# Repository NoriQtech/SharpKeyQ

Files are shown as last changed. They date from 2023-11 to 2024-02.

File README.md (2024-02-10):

## はじめに
このプロジェクトは、[engineers@work](https://eaw.app/) によって開発された SharpKey Multi HID Interface について、DIY用のPCB基板を設計し、動作/検証をする試みです。

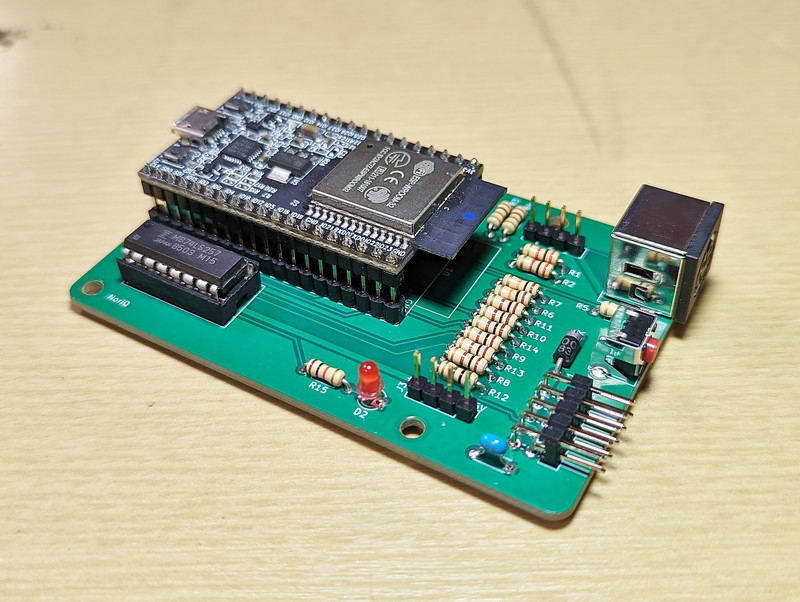
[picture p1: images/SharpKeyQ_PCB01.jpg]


海外のコアな8BitレトロPCファンが日本のユニークな8Bitパソコンを使いこなすために、日夜、解析・研究を行い、今も新しいプロダクトを生み出していることに敬意を表します。

## オリジナル
SharpKey Multi HID Interface のオリジナルプロジェクトについては、下記を参照してください。

* [engineers@work](https://eaw.app/)
* [SharpKey Multi-HID Interface](https://eaw.app/sharpkey/)
* [ユーザーマニュアル](https://eaw.app/sharpkey-usermanual/)
* [テクニカルガイド](https://eaw.app/sharpkey-technicalguide/)
* [GitHub](https://github.com/pdsmart)

## このプロジェクト
このプロジェクトはオリジナルコードからビルド可能な状態に修正を加えたものです。
機能は全てオリジナルに準じます。
また、回路図や基板デザインはDIY可能な設計に置き換えられています。

詳細は下記を参照してください。

[JunkQ yard SharpKeyQ](https://junkqyard.blogspot.com/p/sharpkeyq.html)

## アップデート
2024-02-09 MZ-5665モジュールの対応<br/>
2023-11-26 最初のコミット

## ライセンス
オリジナルライセンスに基づき、SharpKey Multi HID Interface の設計、ハードウェアおよびソフトウェアは、GNU Public License v3 に基づいてライセンスされています。

## The Gnu Public License v3
The source and binary files in this project marked as GPL v3 are free software: you can redistribute it and-or modify it under the terms of the GNU General Public License as published by the Free Software Foundation, either version 3 of the License, or (at your option) any later version.

The source files are distributed in the hope that it will be useful, but WITHOUT ANY WARRANTY; without even the implied warranty of MERCHANTABILITY or FITNESS FOR A PARTICULAR PURPOSE. See the GNU General Public License for more details.

You should have received a copy of the GNU General Public License along with this program. If not, see http://www.gnu.org/licenses/.

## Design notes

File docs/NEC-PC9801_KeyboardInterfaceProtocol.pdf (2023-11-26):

Copyright (C) 1994,1995,1996,1997 Terumasa KODAKA, Takeshi KONO

■ Keyboard interface
Target normal, high resolution, PC-98LT / HA
Tip 8251A (equivalent)
Explanation o In the PC-9800 series, the key input information on the keyboard is a serial signal.
It is sent to the main body at (fixed at 19200bps). Keyboard I / F 8251A (equivalent) is a key input Upon receiving the information, an INT 09h interrupt is generated and the key input is software. Notify (BIOS, etc.).
- Even with models with integrated keyboard and main unit, such as 98NOTE, PC-98LT, HA, etc.
The keyboard and keyboard I / F communicate serially in the same way as a desktop machine.
With the u 98NOTE series, you can connect a full keyboard to the numeric keypad connector. It is possible.
- In the PC-9800 series, the TXD signal line of 8251 is RST # (keyboard connector pin 1). Connected to and originally used for keyboard reset, but with a new key
The board now uses this to send commands.
- For models equipped with a new keyboard, it is possible to send commands to the keyboard. can. [CAPS], [Kana], [NUM] Key lock status acquisition and lock status control,
You can change the key repeat interval.
- The following keyboards are valid for the PC-9800 series.
---------------- + --------------------------------- -------------Old keyboard |
+ -------------- + ---------------------------------- ------------
PC-98LT | [BS], [ROLL UP], [ROLL DOWN], [DEL], [HELP], [COPY]
| | There is no key, but you can substitute it with the following operation.
| | [BS], [DEL] = [DEL BS]
| | [HELP] = [CTRL] + [SHIFT] + [H]
| | [ROLL UP] = [CTRL] + [SHIFT] + [↑]
| | [ROLL DOWN] = [CTRL] + [SHIFT] + [↓]
| | [COPY] = [CTRL] + [SHIFT] + [P]
+ -------------- + ---------------------------------- ------------
| High resolution | PC-98XA / XL / XL ^ 2
+ -------------- + ---------------------------------- ------------
| No NFER | PC-9801 1st generation ・ | E ・ | F ・ | M
+ -------------- + ---------------------------------- ------------
| Others | PC-9801 Other than the first generation, E, F, M
-+ -------------- + --------------------------------- -------------New keyboard |
+ -------------- + ---------------------------------- ------------
| 98NOTE | 98NOTE series
+ -------------- + ---------------------------------- ------------
| PC-9801-98 | Easy keyboard
+ -------------- + ---------------------------------- ------------
| PC-9801-106 | 98 Standard keyboard (Windows key, no menu key)
+ -------------- + ---------------------------------- ------------
PC-9801-114 | PC-PTOS keyboard
+ -------------- + ---------------------------------- ------------
| PC-9801-115 | Bungo DP Keyboard
+ -------------- + ---------------------------------- ------------
PC-9801-116 | 106 keyboard
+ -------------- + ---------------------------------- ------------
| PC-9801-119 | 98 Standard keyboard (Windows key, menu key available)
+ -------------- + ---------------------------------- ------------
| Others | Equivalent to PC-9801-106, PC-9801T-03
-+ -------------- + --------------------------------- -------------Related I / O 0000h bit 1
INT 18h --Function 00 ～ 09h
INT 09h (external interrupt)
0000: 0502 ～ 053Ah

I / O 0041h
Name keyboard interface
function
[READ] Read received data
bit 7-0: Make / Break Code, Status 00-7Fh = Makeup code
80 ～ FFh = Break code
FAh = ACK
FCh = NACK
[WRITE] Write transmission data
bit 7-0: Down command
-------- + ------------------------------------------- ----------
Command | Contents
-------- + ------------------------------------------- ----------
95h | Extended key setting ■ [PC-9801-98 ･ 119] (Undocumented)
| * Output parameters in the 2nd byte
| bit 7 ～ 0:
| 00h = Normal
| 03h = Windows key, application key valid
| ■ [PC-9801-119]
-------- + ------------------------------------------- ----------
96h | Mode identification ■ [PC-9801-98] (Undocumented)
| * A0h, 86h is returned in automatic conversion mode
| * A0h, 85h is returned in normal mode
-------- + ------------------------------------------- ----------
99h | Unknown (Undocumented)
| * FBh is returned
-------- + ------------------------------------------- ----------
9Ch | Keyboard repeat speed setting (Undocumented)
| * Output parameters in the 2nd byte
| bit 7: unused

| bit 6,5: Delay
| 11b = 1000ms
| 10b = 500ms
| 01b = 500ms (default)
| 00b = 250ms
| bit 4 ~ 0: Repeat speed
| 11111b = lowest speed
| 00001b = fastest (default)
-------- + ------------------------------------------- ----------
9Dh | Unknown ■ [PC-9801NS / T] (Undocumented)
| * Output parameters in the 2nd byte
| 00h = Unknown
| 01h = Unknown
-------- + ------------------------------------------- ----------
9Dh | Keyboard LED reading (Undocumented)
| * Send 60h to the 2nd byte
| * LED status is sent in the following format
| bit 7-4: unused
| bit 3: [Kana] LED
| bit 2: [CAPS] LED
| bit 0: [NUM] LED
| 1 = ON
| 0 = OFF
-------- + ------------------------------------------- ----------
9Dh | Keyboard LED settings
| * Output parameters in the 2nd byte
| bit 7-4: Always 0111b
| bit 3: [Kana] LED
| bit 2: [CAPS] LED
| bit 0: [NUM] LED (Undocumented)
| 1 = ON
| 0 = OFF
-------- + ------------------------------------------- ----------
9Eh | Unknown (Undocumented)
-------- + ------------------------------------------- ----------
9Fh | Keyboard type identification
| * A0h, 80h is returned on the new keyboard
-------- + ------------------------------------------- ----------Explanation o Get the make / break code from the keyboard.
- Issue a downlink command to the keyboard. Related I / O 0041h

I / O 0043h
Name keyboard interface
function
[READ] ■ Meaning of bits when reading status bit 7: DSR input terminal
1 = HIGH level
0 = LOW level
* Indicates the status of pin 6 of the keyboard connector. (Undocumented) bit 6: SYNC / BRK
1 = Break detection
0 = None
* Does not occur as long as you have a regular handshake with the keyboard. bit 5: Framing error (FE) detection
1 = Yes
0 = None
bit 4: Overrun error (OE) detection
1 = Yes
0 = None
* Does not occur as long as you have a regular handshake with the keyboard. bit 3: Parity error (PE) detection
1 = Yes
0 = None
bit 2: TxEMP (end of transmission)
bit 1: RxRDY (data reception)
bit 0: TxRDY (can be sent)

[WRITE] ■ Meaning of bits when writing command words
bit 7: enter hunt phase
* Do not use the keyboard I / F because it is synchronized communication. Set to 0. bit 6: 8251A reset
1 = do
0 = No
bit 5: RTS terminal control
1 = RDY # signal line is always inactive
0 = RDY # signal line follows the state of RxRDY
* For keyboard I / F, RDY # signal line (keyboard connector pin 3) Control the operation. It has the following meaning.
bit 4: Clear error flag
1 = Clear FE, OE, PE of 8251A
0 = Do not clear the error
bit 3: TxDATA break transmission
1 = RST # Set signal line to LOW level
0 = RST # Set signal line to HIGH level
* For keyboard I / F, RST # signal line (keyboard connector pin 1)
Control the operation. RST # signal line to LOW level for a period of 13 μs or more Then, the CPU in the keyboard is reset.
bit 2: Acceptance
1 = Receive data from the keyboard
0 = No data received from keyboard
* The keyboard I / F operates as follows. bit 1: DTR signal
1 = Set RTY # signal to HIGH level

0 = RTY # Set signal to LOW level
* For keyboard I / F, RTY # signal line (keyboard connector pin 5) Control the operation. Usually HIGH. When LOW, the data on the keyboard Request a resend.
bit 0: Send permission
1 = RST # Send data from signal line
0 = RST # Do not send data from the signal line
* On the keyboard I / F, issue a downlink command for the keyboard. When using the RST # signal line. Set to 1 when sending a command. [WRITE] ■ Meaning of bits when mode is written
bit 7,6: ST2, ST1 (number of transmission stop bits)
Set 01b (1 bit)
bit 5,4: P1, P0 (parity generation / check)
Set 01b (odd parity)
bit 3,2: L1, L0 (character length)
Set 11b (8 bits)
bit 1,0: B1, B0 (baud rate)
Set 10b (16x clock)

Explanation o Set the mode of the 8251 equivalent used for the keyboard interface. Related I / O 0043h

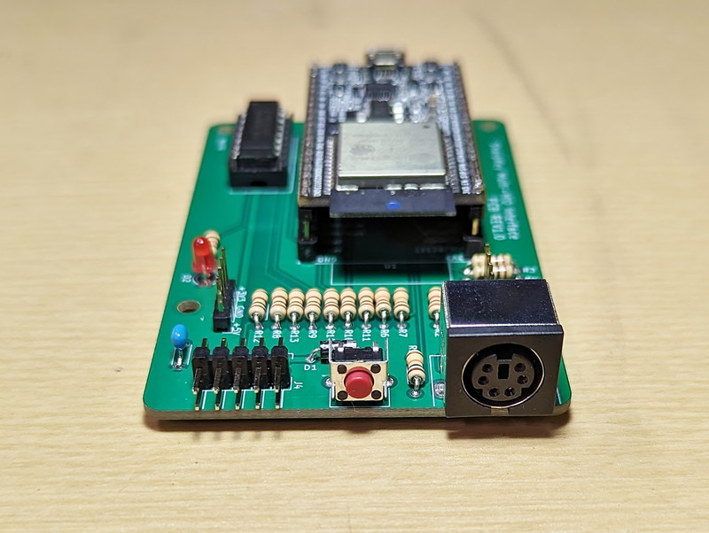
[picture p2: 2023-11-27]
images/SharpKeyQ_PCB02.jpg

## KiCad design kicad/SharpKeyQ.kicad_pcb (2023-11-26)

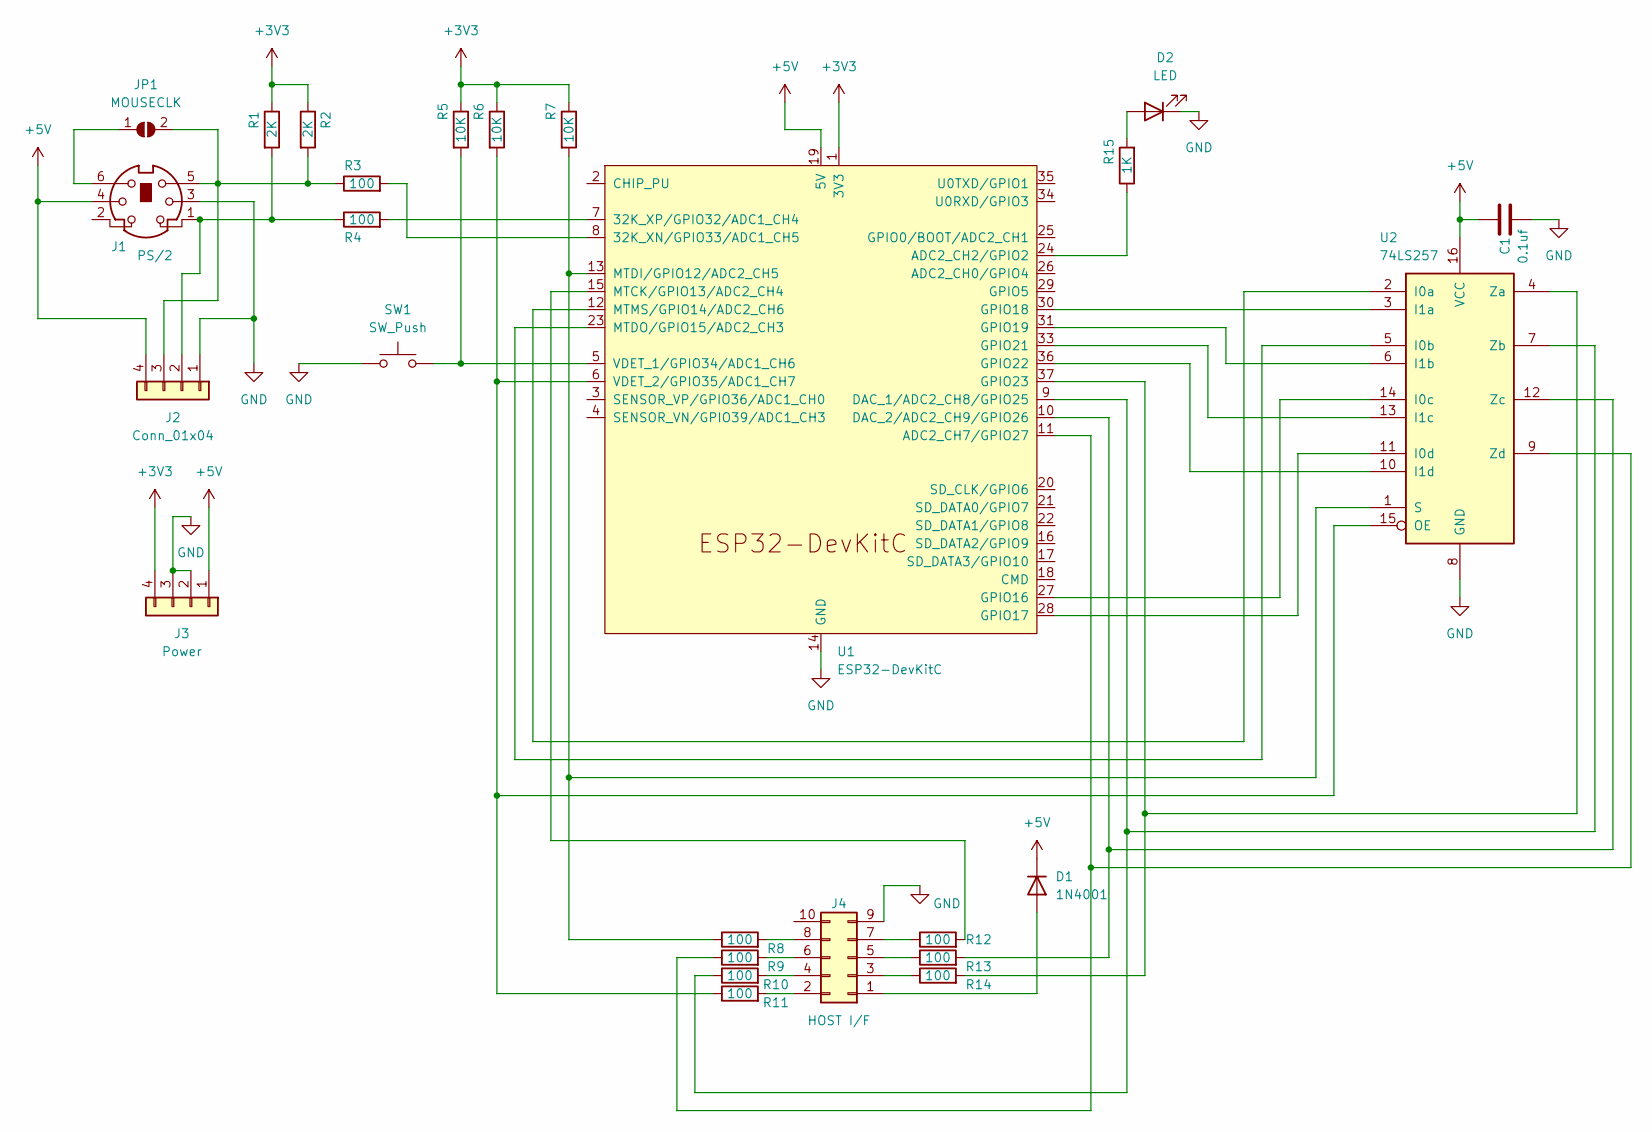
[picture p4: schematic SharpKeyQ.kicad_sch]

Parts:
C1: 0.1uf; C_Disc_D4.3mm_W1.9mm_P5.00mm
D1: 1N4001; D_DO-34_SOD68_P7.62mm_Horizontal
D2: LED; LED_D3.0mm
J1: PS/2; Connector_Mini-DIN_Female_6Pin_2rows
J2: Conn_01x04; PinHeader_1x04_P2.54mm_Vertical
J3: Power; PinHeader_1x04_P2.54mm_Vertical
J4: HOST I/F; PinHeader_2x05_P2.54mm_Horizontal
JP1: MOUSECLK; SolderJumper-2_P1.3mm_Open_RoundedPad1.0x1.5mm
R1, R2: 2K; R_Axial_DIN0204_L3.6mm_D1.6mm_P7.62mm_Horizontal
R3, R4, R8, R9, R10, R11, R12, R13, R14: 100; R_Axial_DIN0204_L3.6mm_D1.6mm_P7.62mm_Horizontal
R5, R6, R7: 10K; R_Axial_DIN0204_L3.6mm_D1.6mm_P7.62mm_Horizontal
R15: 1K; R_Axial_DIN0204_L3.6mm_D1.6mm_P7.62mm_Horizontal
SW1: SW_Push; SW_Tactile_SKHH_Angled
U1: ESP32-DevKitC
U2: 74LS257; DIP-16_W7.62mm_Socket

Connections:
+3V3: J3.4, R1.1, R2.1, R5.1, R6.1, R7.1, U1.1 (3V3)
+5V: C1.1, D1.1 (K), J1.4, J2.4, J3.1, U1.19 (5V), U2.16 (VCC)
GND: C1.2, D2.1 (K), J1.3, J2.1, J3.2, J3.3, J4.9, SW1.2, U1.14 (GND), U1.32 (GND), U1.38 (GND), U2.8 (GND)
unnamed: D1.2 (A), J4.1
unnamed: D2.2 (A), R15.2
unnamed: J1.1, J2.2, R1.2, R4.1
unnamed: J1.5, J2.3, JP1.2 (B), R2.2, R3.1
unnamed: J4.2, R11.2
unnamed: J4.3, R14.1
unnamed: J4.4, R10.2
unnamed: J4.5, R13.1
unnamed: J4.6, R9.2
unnamed: J4.7, R12.1
unnamed: J4.8, R8.2
unnamed: J1.6, JP1.1 (A)
unnamed: R3.2, U1.8 (32K_XN/GPIO33/ADC1_CH5)
unnamed: R4.2, U1.7 (32K_XP/GPIO32/ADC1_CH4)
unnamed: R15.1, U1.24 (ADC2_CH2/GPIO2)
unnamed: R9.1, U1.11 (ADC2_CH7/GPIO27), U2.9 (Zd)
unnamed: R10.1, U1.9 (DAC_1/ADC2_CH8/GPIO25), U2.7 (Zb)
unnamed: R13.2, U1.10 (DAC_2/ADC2_CH9/GPIO26), U2.12 (Zc)
unnamed: U1.27 (GPIO16), U2.14 (I0c)
unnamed: U1.28 (GPIO17), U2.11 (I0d)
unnamed: U1.30 (GPIO18), U2.3 (I1a)
unnamed: U1.31 (GPIO19), U2.6 (I1b)
unnamed: U1.33 (GPIO21), U2.13 (I1c)
unnamed: U1.36 (GPIO22), U2.10 (I1d)
unnamed: R14.2, U1.37 (GPIO23), U2.4 (Za)
unnamed: R12.2, U1.15 (MTCK/GPIO13/ADC2_CH4)
unnamed: R7.2, R8.1, U1.13 (MTDI/GPIO12/ADC2_CH5), U2.1 (S)
unnamed: U1.23 (MTDO/GPIO15/ADC2_CH3), U2.5 (I0b)
unnamed: U1.12 (MTMS/GPIO14/ADC2_CH6), U2.2 (I0a)
unnamed: R5.2, SW1.1, U1.5 (VDET_1/GPIO34/ADC1_CH6)
unnamed: R6.2, R11.1, U1.6 (VDET_2/GPIO35/ADC1_CH7), U2.15 (OE)

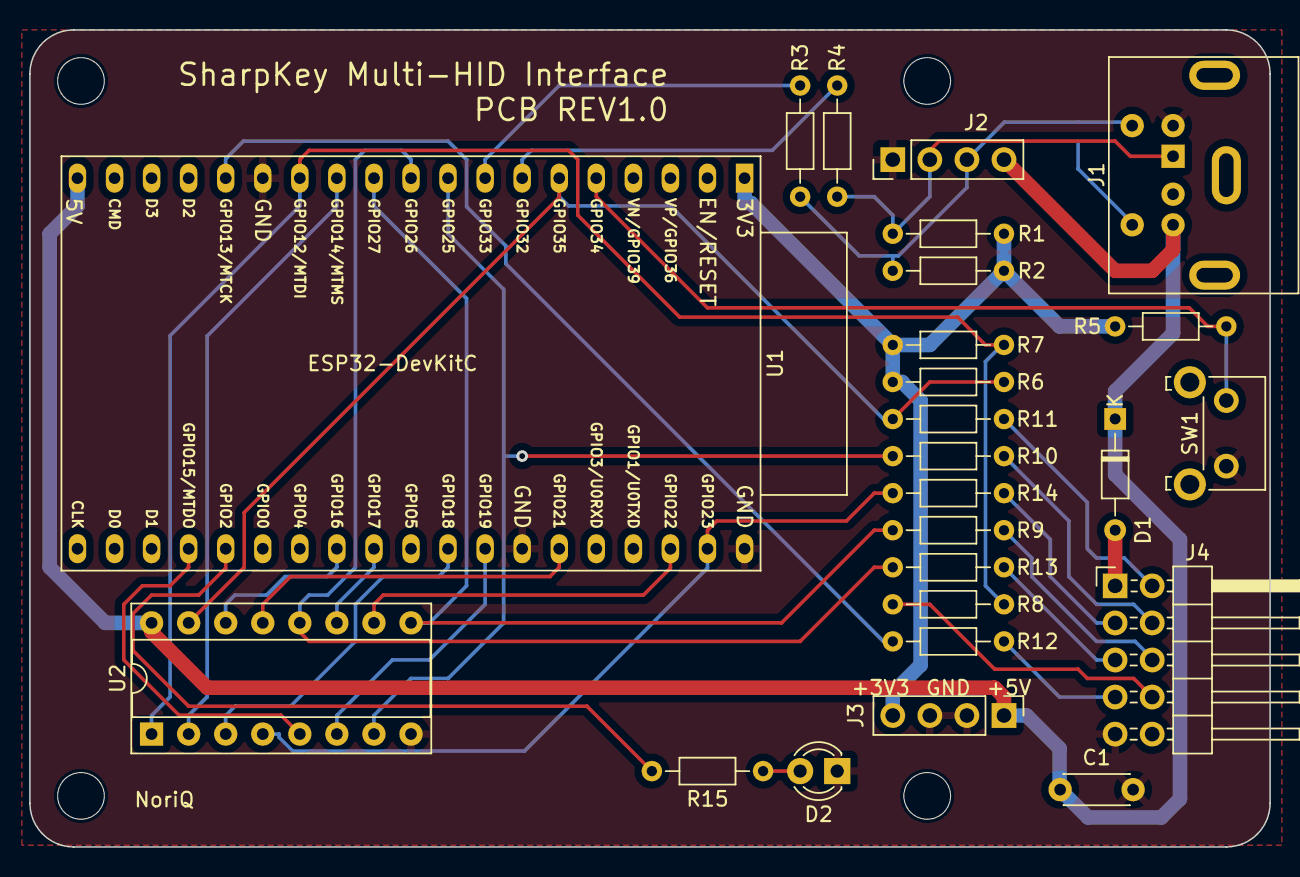
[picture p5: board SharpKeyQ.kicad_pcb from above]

Board: 2 copper layers, 85.0 x 56.0 mm, 30 parts (1 on the bottom side), 34 nets.

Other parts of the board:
REF1, REF2, REF3, REF4: MountingHole_3.2mm_M3

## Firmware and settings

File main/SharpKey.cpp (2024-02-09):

/////////////////////////////////////////////////////////////////////////////////////////////////////////
//
// Name:            SharpKey.cpp
// Created:         Jan 2022
// Version:         v1.0
// Author(s):       Philip Smart
// Description:     HID (PS/2, Bluetooth) to Sharp Keyboard and Mouse Interface.
//                  This source file contains the application logic to interface several Sharp MZ/X
//                  machines to a HID (PS/2 keyboard, PS/2 Mouse, Bluetooth Keyboard/Mouse). The type
//                  of host is determined by the host i/o lines  and the necessary control threads 
//                  instantiated accordingly.
//
//                  Please see the individual classes (singleton obiects) for a specific host logic.
//
//                  The application uses the Espressif Development environment with Arduino components.
//                  This is necessary for the PS2KeyAdvanced class, which may in future be converted to
//                  use esp-idf library calls rather than Arduino. I wrote the PS2Mouse class using
//                  Arduino as well, so both will need conversion eventually.
//
//                  The Espressif environment is necessary in order to have more control over the build.
//                  It is important, for timing, that Core 1 is dedicated to the MZ 2599/2800 Interface 
//                  logic due to timing constraints and Core 0 is used for all RTOS/Interrupts tasks. 
//                  Other host interface classes freely use both cores.
//
//                  The application is configured via the Kconfig system. Use 'idf.py menuconfig' to 
//                  configure.
// Credits:         
// Copyright:       (c) 2022 Philip Smart <philip.smart@net2net.org>
//
// History:         Jan 2022 - Initial write.
//                  Feb 2022 - Updates and fixes. Added logic to detect PS/2 disconnect and reconnect,
//                             added 3 alternative maps selected by ALT+F1 (MZ2500), ALT+F2(MZ2000)
//                             ALT+F3(MZ80B) due to slight differences in the key layout.
//                             Added framework for wifi so that the interface can enter AP mode to
//                             acquire local net parameters then connect to local net. Needs the web
//                             interface writing.
//                  Mar 2022 - Split from mz25key and modularised to allow multiple host targets.
//                  Apr 2022 - Rewrote the application as C++ classes, the host interfaces are based
//                             on a Base class (KeyInterface) which virtualises the interface and
//                             provides some base methods and variables, each host inherits the Base class
//                             to form individual singleton objects.
//                  Apr 2022 - Added X1, X68000 Keyboard functionality and Mouse functionality.
//                  Apr 2022 - Started on tests for using Bluetooth, moved all input devices (Human
//                             Input Device) into its own class to encapsulate PS/2 Keyboard, Mouse and
//                             Bluetooth Keyboard/Mouse.
//            v1.01 May 2022 - More objectifying the fundamental components to make it easier to upgrade.
//            v1.02 May 2022 - Initial release version.
//            v1.03 May 2022 - Added feature security and efuse build data.
//            v1.04 Jun 2022 - Reworked the Wifi so that when requested, the SharpKey reboots and 
//                             immediately starts up in WiFi mode without enabling BT or hardware I/F.
//                             This is necessary due to shared antenna in the ESP32 and also clashes
//                             in the IDF library stack.
//            v1.05 May 2023 - Fine tune the PC-9801/X68000 detection algorithm.
//
// Notes:           See Makefile to enable/disable conditional components
//
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
#include <stdio.h>
#include <stdlib.h>
#include <string.h>
#include <fstream>
#include <sstream>
#include <iostream>
#include <vector>
#include <iterator>
#include "freertos/FreeRTOS.h"
#include "freertos/task.h"
#include "esp_log.h"
#include "esp_system.h"
#include "esp_efuse.h"
#include "esp_efuse_table.h"
#include "esp_efuse_custom_table.h"
#include "nvs_flash.h"
#include "nvs.h"
#include "Arduino.h"
#include "driver/gpio.h"
#include "soc/timer_group_struct.h"
#include "soc/timer_group_reg.h"
#include "soc/soc.h"
#include "soc/rtc_cntl_reg.h"
#include "sdkconfig.h"
#include "MZ2528.h"
#include "X1.h"
#include "X68K.h"
#include "MZ5665.h"
#include "PC9801.h"
#include "Mouse.h"
#include "HID.h"
#include "NVS.h"
#include "WiFi.h"

//////////////////////////////////////////////////////////////////////////
// Important:
//
// All configuration is performed via the 'idf.py menuconfig' command.
// The file 'sdkconfig' contains the configured parameter defines.
//////////////////////////////////////////////////////////////////////////

// Constants.
#define SHARPKEY_NAME                  "SharpKey"
#define SHARPKEY_VERSION               1.04
#define SHARPKEY_MODULES               "SharpKey MZ2528 X1 X68K MZ5665 PC9801 Mouse KeyInterface HID NVS LED SWITCH WiFi FilePack"

// Tag for ESP main application logging.
#define MAINTAG                        "sharpkey"

// LittleFS default parameters.
#define LITTLEFS_DEFAULT_PATH          "/littlefs"
#define LITTLEFS_DEFAULT_PARTITION     "filesys"

// Structure for configuration information stored in NVS.
struct SharpKeyConfig {
    struct {
        uint8_t                 bootMode;               // Flag to indicate the mode SharpKey should boot into.
                                                        // 0 = Interface, 1 = WiFi (configured), 2 = WiFi (default).
    } params;
} sharpKeyConfig;

// Overloads for the EFUSE Custom MAC definitions. Limited Efuse space and Custom MAC not needed in eFuse in this design
// so we overload with custom flags.
// 0-7 Reserved
// 8-15 defined as Base configuration and enhanced set 1.
static const esp_efuse_desc_t ENABLE_BT[] = {
    {EFUSE_BLK3, 8, 1},
};
static const esp_efuse_desc_t ENABLE_MZ5665[] = {
    {EFUSE_BLK3, 9, 1},
};
static const esp_efuse_desc_t ENABLE_PC9801[] = {
    {EFUSE_BLK3, 10, 1},
};
static const esp_efuse_desc_t ENABLE_MOUSE[] = {
    {EFUSE_BLK3, 11, 1},
};
static const esp_efuse_desc_t ENABLE_X68000[] = {
    {EFUSE_BLK3, 12, 1},
};
static const esp_efuse_desc_t ENABLE_X1[] = {
    {EFUSE_BLK3, 13, 1},
};
static const esp_efuse_desc_t ENABLE_MZ2800[] = {
    {EFUSE_BLK3, 14, 1},
};
static const esp_efuse_desc_t ENABLE_MZ2500[] = {
    {EFUSE_BLK3, 15, 1},
};
const esp_efuse_desc_t* ESP_EFUSE_ENABLE_BT[] = {
    &ENABLE_BT[0],
    NULL
};
const esp_efuse_desc_t* ESP_EFUSE_ENABLE_MZ5665[] = {
    &ENABLE_MZ5665[0],
    NULL
};
const esp_efuse_desc_t* ESP_EFUSE_ENABLE_PC9801[] = {
    &ENABLE_PC9801[0],
    NULL
};
const esp_efuse_desc_t* ESP_EFUSE_ENABLE_X68000[] = {
    &ENABLE_X68000[0],
    NULL
};
const esp_efuse_desc_t* ESP_EFUSE_ENABLE_X1[] = {
    &ENABLE_X1[0],
    NULL
};
const esp_efuse_desc_t* ESP_EFUSE_ENABLE_MZ2800[] = {
    &ENABLE_MZ2800[0],
    NULL
};
const esp_efuse_desc_t* ESP_EFUSE_ENABLE_MZ2500[] = {
    &ENABLE_MZ2500[0],
    NULL
};
const esp_efuse_desc_t* ESP_EFUSE_ENABLE_MOUSE[] = {
    &ENABLE_MOUSE[0],
    NULL
};

// Revision control, stored in EFUSE block. 
typedef struct {
    uint16_t   hardwareRevision;    // Hardware revision, stored as x/1000 - gives range 0.000 - 64.999
    uint16_t   serialNo;            // Serial Number of the device.
    uint8_t    buildDate[3];        // Build date of the hardware.
    bool       disableRestrictions; // Flag to indicate all firmware restrictions should be disabled.
    bool       enableMZ2500;        // Flag to indicate MZ-2500 functionality should be enabled.
    bool       enableMZ2800;        // Flag to indicate MZ-2800 functionality should be enabled.
    bool       enableX1;            // Flag to indicate X1 functionality should be enabled.
    bool       enableX68000;        // Flag to indicate X68000 functionality should be enabled.
    bool       enableMouse;         // Flag to indicate Mouse functionality should be enabled.
    bool       enableBluetooth;     // Flag to indicate Bluetooth functionality should be enabled.
    bool       enableMZ5665;        // Flag to indicate MZ-6500 functionality should be enabled.
    bool       enablePC9801;        // Flag to indicate NEC PC-9801 functionality should be enabled.
} t_EFUSE;

// Method to check the efuse coding scheme is disabled. For this project it should be disabled.
bool checkEFUSE(void)
{
    // Locals.
    bool    result = false;
    size_t  secureVersion = 0;

    // Check the efuse coding scheme, should be NONE and the security version should be 0 for this project.
    esp_efuse_coding_scheme_t coding_scheme = esp_efuse_get_coding_scheme(EFUSE_BLK3);
    if(coding_scheme == EFUSE_CODING_SCHEME_NONE)
    {
        ESP_ERROR_CHECK(esp_efuse_read_field_cnt(ESP_EFUSE_SECURE_VERSION, &secureVersion));
        if(secureVersion == 0)
        {
            result = true;
        }
    }

    // True = efuse present and correct, false = not recognised.
    return(result);
}

// Method to read out the stored configuration from EFUSE into the configuration structure 
// for later appraisal.
bool readEFUSE(t_EFUSE &sharpkeyEfuses)
{
    // Locals.
    bool       result = true;

    // Manually read each fuse value into the given structure, any failures treat as a complete failure.
    result = esp_efuse_read_field_blob(ESP_EFUSE_HARDWARE_REVISION,    &sharpkeyEfuses.hardwareRevision, 16) == ESP_OK   ? result : false; sharpkeyEfuses.hardwareRevision = __builtin_bswap16(sharpkeyEfuses.hardwareRevision);
    result = esp_efuse_read_field_blob(ESP_EFUSE_SERIAL_NO,            &sharpkeyEfuses.serialNo, 16) == ESP_OK           ? result : false; sharpkeyEfuses.serialNo = __builtin_bswap16(sharpkeyEfuses.serialNo);
    result = esp_efuse_read_field_blob(ESP_EFUSE_BUILD_DATE,           &sharpkeyEfuses.buildDate, 24) == ESP_OK          ? result : false;
    result = esp_efuse_read_field_blob(ESP_EFUSE_DISABLE_RESTRICTIONS, &sharpkeyEfuses.disableRestrictions, 1) == ESP_OK ? result : false;
    result = esp_efuse_read_field_blob(ESP_EFUSE_ENABLE_BT,            &sharpkeyEfuses.enableBluetooth, 1) == ESP_OK     ? result : false;
    result = esp_efuse_read_field_blob(ESP_EFUSE_ENABLE_MZ2500,        &sharpkeyEfuses.enableMZ2500, 1) == ESP_OK        ? result : false;
    result = esp_efuse_read_field_blob(ESP_EFUSE_ENABLE_MZ2800,        &sharpkeyEfuses.enableMZ2800, 1) == ESP_OK        ? result : false;
    result = esp_efuse_read_field_blob(ESP_EFUSE_ENABLE_X1,            &sharpkeyEfuses.enableX1, 1) == ESP_OK            ? result : false;
    result = esp_efuse_read_field_blob(ESP_EFUSE_ENABLE_X68000,        &sharpkeyEfuses.enableX68000, 1) == ESP_OK        ? result : false;
    result = esp_efuse_read_field_blob(ESP_EFUSE_ENABLE_MZ5665,        &sharpkeyEfuses.enableMZ5665, 1) == ESP_OK        ? result : false;
    result = esp_efuse_read_field_blob(ESP_EFUSE_ENABLE_PC9801,        &sharpkeyEfuses.enablePC9801, 1) == ESP_OK        ? result : false;
    result = esp_efuse_read_field_blob(ESP_EFUSE_ENABLE_MOUSE,         &sharpkeyEfuses.enableMouse, 1) == ESP_OK         ? result : false;

    // Return true = successful read, false = failed to read efuse or values.
    return(result);
}

// Method to write the configuration to one-time programmable FlashRAM EFuses. This setting persists for the life of the SharpKey
// and so minimal information is stored which cant be wiped, everything else uses reprogrammable FlashRAM via NVS.
bool writeEFUSE(t_EFUSE &sharpkeyEfuses)
{
    // Locals.
    bool    result = true;
#ifdef CONFIG_EFUSE_VIRTUAL

    // Write out the configuration structure member at a time.
    result = esp_efuse_write_field_blob(ESP_EFUSE_HARDWARE_REVISION,    &sharpkeyEfuses.hardwareRevision, 16) == ESP_OK   ? result : false;
    result = esp_efuse_write_field_blob(ESP_EFUSE_SERIAL_NO,            &sharpkeyEfuses.serialNo, 16) == ESP_OK           ? result : false;
    result = esp_efuse_write_field_blob(ESP_EFUSE_BUILD_DATE,           &sharpkeyEfuses.buildDate, 24) == ESP_OK          ? result : false;
    result = esp_efuse_write_field_blob(ESP_EFUSE_DISABLE_RESTRICTIONS, &sharpkeyEfuses.disableRestrictions, 1) == ESP_OK ? result : false;
    result = esp_efuse_write_field_blob(ESP_EFUSE_ENABLE_BT,            &sharpkeyEfuses.enableBluetooth, 1) == ESP_OK     ? result : false;
    result = esp_efuse_write_field_blob(ESP_EFUSE_ENABLE_MZ2500,        &sharpkeyEfuses.enableMZ2500, 1) == ESP_OK        ? result : false;
    result = esp_efuse_write_field_blob(ESP_EFUSE_ENABLE_MZ2800,        &sharpkeyEfuses.enableMZ2800, 1) == ESP_OK        ? result : false;
    result = esp_efuse_write_field_blob(ESP_EFUSE_ENABLE_X1,            &sharpkeyEfuses.enableX1, 1) == ESP_OK            ? result : false;
    result = esp_efuse_write_field_blob(ESP_EFUSE_ENABLE_X68000,        &sharpkeyEfuses.enableX68000, 1) == ESP_OK        ? result : false;
    result = esp_efuse_write_field_blob(ESP_EFUSE_ENABLE_MZ5665,        &sharpkeyEfuses.enableMZ5665, 1) == ESP_OK        ? result : false;
    result = esp_efuse_write_field_blob(ESP_EFUSE_ENABLE_PC9801,        &sharpkeyEfuses.enablePC9801, 1) == ESP_OK        ? result : false;
    result = esp_efuse_write_field_blob(ESP_EFUSE_ENABLE_MOUSE,         &sharpkeyEfuses.enableMouse, 1) == ESP_OK         ? result : false;

#endif // CONFIG_EFUSE_VIRTUAL
    // Return true for success, false for 1 or more failures.
    return(result);
}

// Method to return the application version number.
float version(void)
{
    return(SHARPKEY_VERSION);
}
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
extern "C" void app_main()
{
    // Locals.
    NVS    nvs;

    // Setup hardware and start primary control threads,
    setup(nvs);

    // Loop waiting on callback events and action accordingly.
    while(true)
    {
        // Change in boot mode requires persisting and reboot.
        //
        if(sharpKeyConfig.params.bootMode == 1 || sharpKeyConfig.params.bootMode == 2)
        {
            // Set boot mode to wifi, save and restart.
            //
            ESP_LOGW(MAINTAG, "Persisting WiFi mode.");
            if(nvs.persistData(SHARPKEY_NAME, &sharpKeyConfig, sizeof(struct SharpKeyConfig)) == false)
            {
                ESP_LOGW(SETUPTAG, "Persisting SharpKey configuration data failed, updates will not persist in future power cycles.");
            } else
            // Few other updates so make a commit here to ensure data is flushed and written.
            if(nvs.commitData() == false)
            {
                ESP_LOGW(SETUPTAG, "NVS Commit writes operation failed, some previous writes may not persist in future power cycles.");
            }
            
            // Restart and the SharpKey will come up in Wifi mode.
            esp_restart();
        }

        // Piggy backing off the bootMode is a flag to indicate NVS flash erase and reboot.
        //
        if(sharpKeyConfig.params.bootMode == 255)
        {
            // Close out NVS and erase.
            nvs.eraseAll();

            // Need to reboot as the in-memory config still holds the old settings.
            esp_restart();
        }

        // Sleep, not much to be done other than look at event flags.
        vTaskDelay(500);
    }

    // Lost in space.... this thread is no longer required!
}

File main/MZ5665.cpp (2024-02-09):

/////////////////////////////////////////////////////////////////////////////////////////////////////////
//
// Name:            MZ5665.cpp
// Created:         Apr 2022
// Version:         v1.0
// Author(s):       Philip Smart
// Description:     HID (PS/2 or BT keyboard) to Sharp MZ-5600/MZ-6500 series Interface logic.
//                  This source file contains the singleton class containing logic to obtain
//                  PS/2 or BT scan codes, map them into Sharp MZ-5600/MZ-6500 keys and transmit the key
//                  to the MZ-5600/MZ-6500 host.
//
//                  The class uses a modified version of the PS2KeyAdvanced 
//                  https://github.com/techpaul/PS2KeyAdvanced class from Paul Carpenter.
//
//                  The whole application of which this class is a member, uses the Espressif Development
//                  environment with Arduino components.  This is necessary for the PS2KeyAdvanced class, 
//                  which I may in future convert to use esp-idf library calls rather than Arduino.
//
// Credits:         
// Copyright:       (c) 2022 Philip Smart <philip.smart@net2net.org>
//
// History:         Apr 2022 - Initial framework, waiting on arrival of real machine to progress further.
//            v1.01 Jun 2022 - Updates to reflect changes realised in other modules due to addition of
//                             bluetooth and suspend logic due to NVS issues using both cores.
//            v1.02 Feb 2024 - Updated to actually work by NoriQ.
//
// Notes:           See Makefile to enable/disable conditional components
//
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
#include <stdio.h>
#include <stdlib.h>
#include <string.h>
#include <iostream>
#include <fstream>
#include <sstream>
#include <iomanip>
#include <vector>
#include <map>
#include <filesystem>
#include "freertos/FreeRTOS.h"
#include "freertos/task.h"
#include "freertos/queue.h"
#include "driver/gpio.h"
#include "esp_log.h"
#include "soc/timer_group_struct.h"
#include "soc/timer_group_reg.h"
#include "driver/timer.h"
#include "sys/stat.h"
#include "esp_littlefs.h"
#include "PS2KeyAdvanced.h"
#include "sdkconfig.h"
#include "MZ5665.h"

// Tag for ESP main application logging.
#define                         MAINTAG  "mz5665key"

// FreeRTOS Queue handle to pass messages from the HID Keyboard Mapper into the MZ5665 transmission logic.
static QueueHandle_t            xmitQueue;

// MZ-5600/MZ-6500 Protocol
// ------------------------
//
// The MZ-5600 uses 4-wire serial communication.
//
// Protocol:
//  signal name : 
//  /DC : CPU -> KB  send data
//  /STC : CPU -> KB  strobe
//  /DK : KB -> CPU  send data
//  /SRK : KB -> CPU  request to receive(CPU)
//  /DK and /SRK are open collector outputs.
//
//  KEYBOARD -> CPU
//   Set /SRK to LOW to start interrupt.
//   A strobe signal is output to /STC.
//   Output Extension
//   Output key data Bit[7:0] to /DK.
//   Outputs parity bit to /DK.
//     <E.B><D7><D6><D5><D4><D3><D2><D1><D0><P.B>
//

// Function to push a keycode onto the key queue ready for transmission.
//
void MZ5665::pushKeyToQueue(uint32_t key)
{
    // Locals.
    t_xmitQueueMessage  xmitMsg;
    #define             PUSHKEYTAG "pushKeyToQueue"

    xmitMsg.keyCode = key;
    if( xQueueSend(xmitQueue, (void *)&xmitMsg, 10) != pdPASS)
    {
        ESP_LOGW(PUSHKEYTAG, "Failed to put scancode:%04x into xmitQueue", key);
    }
    return;
}


bool MZ5665::waitSignal(uint32_t mask, bool val, uint64_t timeout)
{
//    ESP_LOGW(MAINTAG, "waitSignal:%08x", mask);
    bool        result = false;
    uint64_t    curTime = 0LL;

    ESP_ERROR_CHECK(timer_set_counter_value(TIMER_GROUP_0, TIMER_0, 0));
    timer_start(TIMER_GROUP_0, TIMER_0);

    for(;;)
    {
        timer_get_counter_value(TIMER_GROUP_0, TIMER_0, &curTime);
        // time out
        if(curTime >= timeout)
        {
            break;
        }
        // match
        if(((REG_READ(GPIO_IN_REG) & mask) != 0 ? true : false) == val)
        {
            result = true;
            break;
        }
    }

    timer_pause(TIMER_GROUP_0, TIMER_0);
    return result;
}

// Method to realise the MZ-5600/MZ-6500 4 wire serial protocol in order to transmit key presses to the
// MZ-5600/MZ-6500.
// This method uses Core 1 and it will hold it in a spinlock as necessary to ensure accurate timing.
// A key is passed into the method via the FreeRTOS Queue handle xmitQueue.
IRAM_ATTR void MZ5665::mzInterface( void * pvParameters )
{
    // Locals.
    t_xmitQueueMessage  rcvMsg;

    // Mask values declared as variables, let the optimiser decide wether they are constants or placed in-memory.
    uint32_t           	MZ56DC_MASK = (1 << CONFIG_HOST_KDB2);
    uint32_t           	MZ56STC_MASK = (1 << CONFIG_HOST_KDB1);
    uint32_t           	MZ56DK_MASK = (1 << CONFIG_HOST_KDB0);
    uint32_t           	MZ56SRK_MASK = (1 << CONFIG_HOST_KDB3);
    uint64_t            delayTimer = 0LL;
    uint64_t            curTime    = 0LL;
    bool                bitPulse = true;
    uint32_t            bitCount = 0;
    bool                bitParity = false;
    enum SYNSTATE {
        SYN_BOOTINIT,
        SYN_IDLE,
        SYN_STARTXMIT,
        SYN_SENDKEY,
        SYN_SENDEB,
        SYN_SENDBIT,
        SYN_SENDPB,
        SYN_ENDXMIT,
        SYN_ERRCHK,
        SYN_RCVCOM,
        SYN_RESET
    } state = SYN_BOOTINIT;

    // Retrieve pointer to object in order to access data.
    MZ5665* pThis = (MZ5665*)pvParameters;

    // Initialise the MUTEX which prevents this core from being released to other tasks.
    pThis->mzMutex = portMUX_INITIALIZER_UNLOCKED;

    // Initial delay needed because the xQueue will assert probably on a suspended task ALL if delay not inserted!
    vTaskDelay(1000);

    // Sign on.
    ESP_LOGW(MAINTAG, "Starting MZ-6500 thread.");


    // init gpio
    gpio_config_t     ioConf;
    ioConf.intr_type    = GPIO_INTR_DISABLE;
    ioConf.mode         = GPIO_MODE_INPUT; 
    ioConf.pull_down_en = GPIO_PULLDOWN_DISABLE;
    ioConf.pull_up_en   = GPIO_PULLUP_ENABLE;
    ioConf.pin_bit_mask = (1ULL<<CONFIG_HOST_KDB2);   // DC 
    gpio_config(&ioConf);
    ioConf.pin_bit_mask = (1ULL<<CONFIG_HOST_KDB1);   // STC
    gpio_config(&ioConf);

    // /DK, /SRK pin is open drain
    ioConf.pull_up_en   = GPIO_PULLUP_DISABLE;
    ioConf.mode         = GPIO_MODE_OUTPUT_OD; 
    ioConf.pin_bit_mask = (1ULL<<CONFIG_HOST_KDB0);   // DK
    gpio_config(&ioConf);
    ioConf.pin_bit_mask = (1ULL<<CONFIG_HOST_KDB3);   // SRK
    gpio_config(&ioConf);


    GPIO.out_w1tc = (MZ56DK_MASK);
    GPIO.out_w1ts = (MZ56SRK_MASK);
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
